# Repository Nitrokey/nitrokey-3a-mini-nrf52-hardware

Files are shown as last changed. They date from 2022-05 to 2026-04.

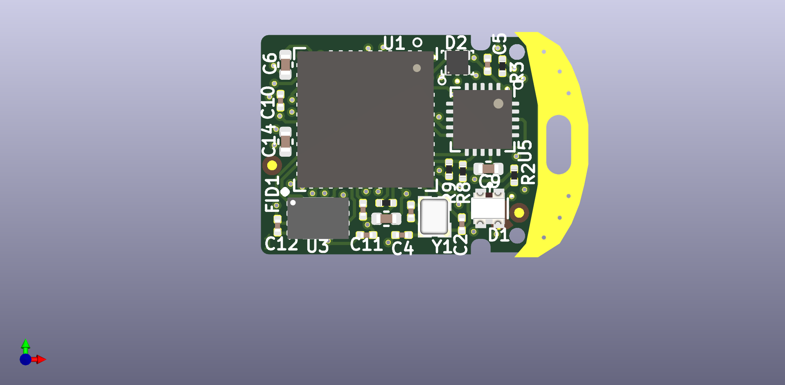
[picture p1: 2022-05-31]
production-data/nk3am112-athene.png

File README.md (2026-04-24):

# Nitrokey 3A Mini and Nitrokey Passkey Hardware

The hardware files of [Nitrokey 3A Mini](https://shop.nitrokey.com/shop/nk3am-nitrokey-3a-mini-149) and [Nitrokey Passkey](https://shop.nitrokey.com/shop/nkpk-nitrokey-passkey-418).
The firmware is [here](https://github.com/Nitrokey/nitrokey-3-firmware).

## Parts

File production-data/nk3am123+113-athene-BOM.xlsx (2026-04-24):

BOM Version 3 | NK3AM123 - Athene | 2026-04-23 | Nitrokey 3A Mini
Component | Description | Part | References | Value | Footprint | Quantity Per PCB | MPN | Manufacturer
1 | C0G cap | C | C1 C2 | 12pF | C_0201_0603Metric | 2
2 | C0G cap | C | C3 | 820pF | C_0201_0603Metric | 1
3 | X5R or X7R cap, 25V | C | C5 C10 C11 C12 | 100nF | C_0201_0603Metric | 4
4 | X5R or X7R cap, 25V | C | C7 C9 | 1u | C_0402_1005Metric | 2
5 | X5R or X7R cap, 10V | C | C6 C14 | 4.7u | C_0402_1005Metric | 2
6 | C0G cap | C | C4 | 100pF | C_0201_0603Metric | 1
7 | TVS Diode | tvs diode | D2 | TPD4S012DRYR | UFDFN-6_1.45x1mm | 1 | TPD4S012DRYR | Texas Instruments
8 | SPI flash IC | spi flash | U3 | GD25Q16CEIGR | FLASH_2x3_USON8 | 1 | GD25Q16EEIGR | GigaDevice Semiconductor (HK) Limited
9 | RGB LED, red/green/blue/anode | LED_RGBA | D1 | LED_RGBA | RGB_LED_606 | 1 | 150066M153000 | Würth
10 | Resistor 1% | R | R1 | 49R9 | R_0201_0603Metric | 1
11 | Resistor 1% | R | R2 | 180R | R_0201_0603Metric | 1
12 | Resistor 1% | R | R3 | 1M | R_0201_0603Metric | 1
13 | Resistor 1% | R | R8 R9 | 4.7k | R_0201_0603Metric | 2
14 | Secure element | SE050 | U5 | SE050 | UQFN-20-1EP_3x3mm_P0.4mm_EP1.85x1.85mm | 1 | SE050C1HQ1/Z01SCZ | NXP
15 | Crystal | Crystal | Y1 | TAXM32M4ZFBCCT2T | Crystal-2mmx1.6mm | 1 | TAXM32M4ZFBCCT2T | TAE
16 | nRF52840 microcontroller | NRF52840-QIAA-R | U1 | NRF52840-QIAA-R | Nordic_AQFN-73-1EP_7x7mm_P0.5mm | 1 | NRF52840-QIAA-R | Nordic Semiconductor ASA

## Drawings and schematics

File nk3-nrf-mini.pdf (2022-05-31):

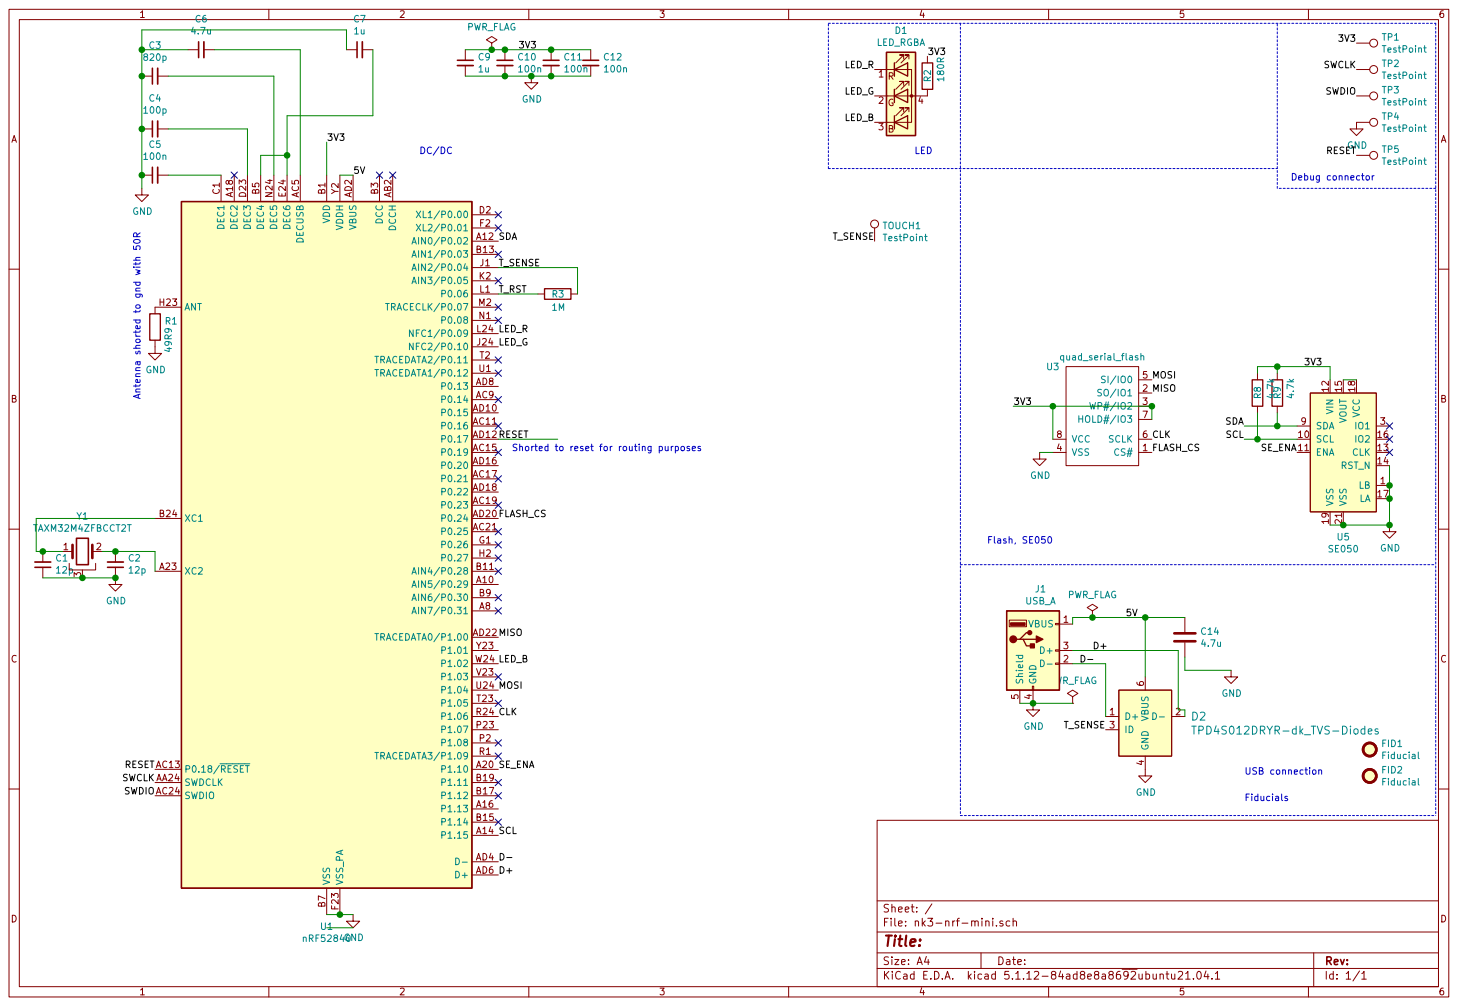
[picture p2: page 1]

TP4 TestPoint TP3 TestPoint TP2 TestPoint TP1 TestPoint R3

Debug connector USB connection

5V Antenna shorted to gnd with 50R

SCL MISO MOSI CLK

Id: 1/1 Title: File: nk3-nrf-mini.sch Sheet: /

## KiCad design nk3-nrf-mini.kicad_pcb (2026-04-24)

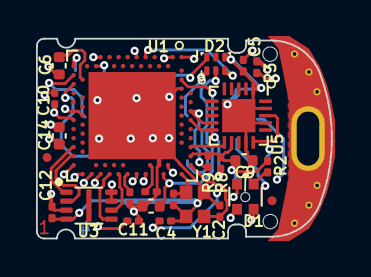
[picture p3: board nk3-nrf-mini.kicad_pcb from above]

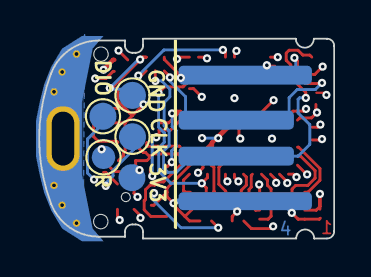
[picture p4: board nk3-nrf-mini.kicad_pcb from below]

Board: 4 copper layers, 16.4 x 11.1 mm, 32 parts (7 on the bottom side), 30 nets.

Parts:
C1, C2: 12p; C_0201_0603Metric
C3: 820p; C_0201_0603Metric
C4: 100p; C_0201_0603Metric
C5, C10, C11, C12: 100n; C_0201_0603Metric
C6, C14: 4.7u; C_0402_1005Metric
C7, C9: 1u; C_0402_1005Metric
D1: LED_RGBA; RGB_LED_606
D2: TPD4S012DRYR-dk_TVS-Diodes; UFDFN-6_1.45x1mm
FID1, FID2: Fiducial; Fiducial_0.5mm_Mask1mm
J1: USB_A; usb-a-pattern
R1: 49R9; R_0201_0603Metric
R2: 180R; R_0201_0603Metric
R3: 1M; R_0201_0603Metric
R8, R9: 4.7k; R_0201_0603Metric
TOUCH1: TestPoint; touchpad-curve
TP1, TP2, TP3, TP4, TP5: TestPoint; TestPoint_Pad_D1.5mm
U1: nRF52840; Nordic_AQFN-73-1EP_7x7mm_P0.5mm
U3: quad_serial_flash; FLASH_2x3_USON8
U5: SE050; UQFN-20-1EP_3x3mm_P0.4mm_EP1.85x1.85mm
Y1: TAXM32M4ZFBCCT2T; Crystal-2mmx1.6mm

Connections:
/3V3: C9.1, C10.1, C11.1, C12.1, R2.1, R8.1, R9.1, TP1.1, U1.A22, U1.AD14, U1.AD23, U1.B1, U1.W1, U3.3, U3.7, U3.8, U5.12
/5V: C14.1, D2.6, J1.1, U1.AD2, U1.Y2
/CLK: U1.R24, U3.6
/D+: D2.2, J1.3, U1.AD6
/D-: D2.1, J1.2, U1.AD4
/FLASH_CS: U1.AD20, U3.1
/LED_B: D1.3, U1.W24
/LED_G: D1.2, U1.J24
/LED_R: D1.1, U1.L24
/MISO: U1.AD22, U3.2
/MOSI: U1.U24, U3.5
/RESET: TP5.1, U1.AC13, U1.AD12
/SCL: R8.2, U1.A14, U5.10
/SDA: R9.2, U1.A12, U5.9
/SE_ENA: U1.A20, U5.11
/SWCLK: TP2.1, U1.AA24
/SWDIO: TP3.1, U1.AC24
/T_RST: R3.2, U1.L1
/T_SENSE: D2.3, R3.1, TOUCH1.1, U1.J1
GND: C1.1, C2.1, C3.1, C4.1, C5.1, C6.1, C7.1, C9.2, C10.2, C11.2, C12.2, C14.2, D2.4, J1.4, R1.2, TP4.1, U1.B7, U1.EP, U1.F23, U3.4, U5.1, U5.14, U5.17, U5.19, U5.21, Y1.3
unnamed: C1.2, U1.B24, Y1.1
unnamed: C2.2, U1.A23, Y1.2
unnamed: C3.2, U1.N24
unnamed: C4.2, U1.D23
unnamed: C5.2, U1.C1
unnamed: C6.2, U1.AC5
unnamed: C7.2, U1.B5, U1.E24
unnamed: D1.4, R2.2
unnamed: R1.1, U1.H23
unnamed: U5.15, U5.18
